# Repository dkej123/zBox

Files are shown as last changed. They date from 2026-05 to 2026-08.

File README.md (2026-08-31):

# zBox

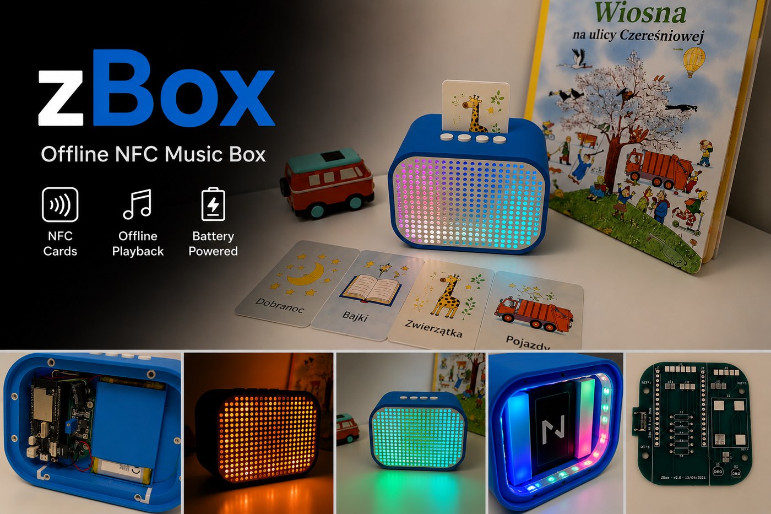
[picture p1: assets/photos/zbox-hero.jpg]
zBox audio box


zBox is an offline-first ESP32 NFC audio box: tap a card to play an MP3 from microSD, use
four physical buttons for playback and modes, and manage music and mappings from a small
FastAPI web portal. Wi-Fi is needed only for provisioning, synchronization, and maintenance.

> [!CAUTION]
> The manufactured PCB and Gerbers are legacy **v2.0 (April 2026)**. They predate the current
> schematic's July load-switch changes and are not a turnkey version of that schematic. A
> build from these Gerbers needs manual off-board wiring; read
> [Hardware status](docs/hardware-status.md) before ordering boards.

## What you need

- [ ] Lolin D32 Pro (ESP32), PN532 SPI NFC module, NS4168 I2S amplifier, and 4–8 Ω speaker
- [ ] MT3608 boost module, 12-pixel WS2812B strip/panel, and four momentary buttons
- [ ] 3.7 V LiPo, USB-C power/charging connection, hookup wire, PCB/protoboard, and solder
- [ ] Printed enclosure parts, M3 heat-set inserts, M3/M4 screws, and suitable filament
- [ ] FAT32 microSD card, NFC cards/tags, and optional Bluetooth headphones or speaker
- [ ] USB cable, soldering tools, multimeter, and a computer with PlatformIO
- [ ] Docker-capable host on the same network (a Raspberry Pi is a good fit)

See the [complete BOM](docs/bom.md) for values, footprints, quantities, and revision notes.

## Quick start

### 1. Clone everything

```bash
git clone --recursive https://github.com/dkej123/zBox.git
cd zBox
```

If you already cloned without submodules, run `git submodule update --init --recursive`.

### 2. Assemble the hardware

Print the [STL enclosure parts](hardware/stl/) and follow the
[printing notes](hardware/printing_tips.md). Wire the modules using the
[hardware reference](docs/hardware.md), accounting for the
[v2.0 PCB limitations](docs/hardware-status.md). Check polarity and shorts before power-up.

### 3. Prepare storage and flash

Format a microSD card as FAT32, insert it into the Lolin D32 Pro, connect USB, then run:

```bash
cd esp32
pio run -e lolin_d32_pro -t upload
cd ..
```

There is no compile-time server address. The device exposes its own sync service over Wi-Fi.

### 4. Start the server

```bash
docker compose up -d --build
curl http://localhost:8000/api/health
```

Open `http://<server-host>:8000`. The optional `ZBOX_IP` environment value is only a fallback;
the preferred setup is saving the device address in the portal.

### 5. Provision Wi-Fi

Hold buttons `A+B` for about two seconds to enter Sync Mode. On first use, join the
`zBox-Sync` Wi-Fi network from a phone or laptop and complete its captive portal with the
credentials for the same network as the server. Note the device IP shown by your router or
serial monitor.

### 6. Add the device and content

In the admin portal:

1. Open **Device**, enter the zBox IP address or `zbox.local`, and save it.
2. Open **Songs** and upload MP3 files.
3. Open **Tags**, scan or enter an NFC UID, name it, and assign a track.
4. Return to **Device** and start synchronization.

When sync finishes, hold `A+B` to return to normal operation. Present the registered card;
playback should start locally from microSD through the NS4168 speaker.

## Controls

| Input | Action |
| --- | --- |
| `A` or `B`, click | Play/pause |
| `A`, double-click | Previous track |
| `B`, double-click | Next track |
| `A`, hold ~2 s | Toggle optional Bluetooth output |
| `B`, hold ~2 s | Toggle NFC Card/Music playback mode |
| `C` / `D`, click | Volume down / up |
| `C`, hold ~2 s | Show battery level |
| `D`, hold ~1 s | Enter deep sleep |
| `A+B`, hold ~2 s | Enter or leave Sync Mode |
| Sleeping: hold `D` ≥400 ms | Wake normally |
| Sleeping: hold `C+D` ≥400 ms | Wake into night-light mode |

The device currently powers down with ESP32 deep sleep. The proposed zero-standby-current
soft latch and mechanical travel switch are design work only; they have not been built or
bench-validated. See [Hardware status](docs/hardware-status.md).

## Repository map

| Path | Contents |
| --- | --- |
| [`esp32/`](esp32/) | PlatformIO firmware and native tests |
| [`server/`](server/) / [`web/`](web/) | FastAPI server and browser admin |
| [`hardware/pcb/kicad/`](hardware/pcb/kicad/) | Current schematic plus legacy v2.0 PCB layout |
| [`hardware/pcb/gerbers/`](hardware/pcb/gerbers/) | Legacy v2.0 manufacturing outputs |
| [`hardware/stl/`](hardware/stl/) | Printable enclosure parts |
| [`hardware/cad/fusion360/step/`](hardware/cad/fusion360/step/) | Editable mechanical STEP export |

## Documentation

- [Build guide](docs/build-guide.md)
- [Bill of materials](docs/bom.md)
- [Hardware status and revision gap](docs/hardware-status.md)
- [Hardware wiring](docs/hardware.md)
- [Firmware](docs/esp32-firmware.md)
- [Server](docs/server.md)

`karty.pdf` and [`cards_images/`](cards_images/) are optional printable card assets. The project
owner holds the rights needed to publish the owner-created card graphics and other media here.

## License

The [MIT license](LICENSE) covers the repository's code, hardware design files, documentation,
and owner-created media unless a file states otherwise. Third-party submodules and dependencies
retain their own licenses. This is a DIY design: independently review electrical and battery
safety before manufacturing or giving a completed device to a child.

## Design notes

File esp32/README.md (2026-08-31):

# zBox ESP32 Firmware

Firmware for the ESP32 Lolin D32 Pro using PlatformIO and the mixed `arduino, espidf` framework setup.

## Quick start

```bash
pio run
pio run -t upload
pio device monitor
```

## Before flashing

- review `ENABLE_LEDS`
- verify the board and partition settings match your hardware
- read the [hardware revision status](../docs/hardware-status.md); the legacy v2.0 PCB needs
  manual wiring for the current firmware's load switches

There is no compile-time server address. Enter Sync Mode with a two-second `A+B` hold,
provision Wi-Fi through the `zBox-Sync` captive portal, and save the device address in the
server's **Device** page. `ZBOX_IP` is only a server-side fallback.

The main project constants live in [`src/zbox_config.h`](src/zbox_config.h).

## Documentation

- [Firmware architecture](../docs/esp32-firmware.md)
- [Hardware notes](../docs/hardware.md)
- [Build guide](../docs/build-guide.md)
- [Server API and deployment](../docs/server.md)

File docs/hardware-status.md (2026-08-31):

# Hardware status and revision gap

The repository intentionally keeps both the manufactured files and the newer design work.
They are not the same revision and must not be presented as interchangeable.

## Status matrix

| Artifact or feature | Status | Builder impact |
| --- | --- | --- |
| PCB layout and Gerbers | **Legacy v2.0, April 2026; manufactured** | Available for reference/reproduction, but older than the current schematic and not turnkey |
| Current KiCad schematic | **Newer design, July 2026 additions** | Documents the intended modules, button pull-ups, and NFC/amplifier load switching |
| Current firmware | **Implements July load-switch control** | Expects `NS_EN=GPIO15`, `NFC_EN=GPIO12`, current button mapping, and deep-sleep sequencing |
| v2.0 manual build | **Possible with off-board wiring** | Builder must add and verify the missing current-schematic circuits manually |
| Soft power latch / travel switch | **Future, unimplemented, unverified** | Excluded from the base build and BOM total; do not assume zero-current off |

## What v2.0 does not contain

The routed [`zbox.kicad_pcb`](../hardware/pcb/kicad/zbox.kicad_pcb) and files in
[`hardware/pcb/gerbers/`](../hardware/pcb/gerbers/) do **not** contain the current schematic's:

- `Q3`, `Q4`;
- `R9` through `R14`;
- `C2` through `C6`;
- `J13`; or
- `NS_EN`, `+3V3_NS`, `NFC_EN`, and `NFC_GND_SW` nets.

The v2.0 PCB instead retains older JBL-era references such as `Q1`, `R3`, `R6`, `R7`, `J10`,
and `J12`. Those are not the current firmware's default NS4168 audio design.

Practically, manufacturing the checked-in Gerbers produces legacy v2.0—not a board matching
the current schematic. The two load switches, button pull-ups, NS4168 connection, decoupling,
and affected nets must be wired off-board and continuity-checked against
[hardware wiring](hardware.md). A future PCB revision should synchronize schematic, layout,
Gerbers, BOM, firmware pins, and a physically tested assembly before it is called turnkey.

## Current power-off behavior

Today, all shutdown paths end in ESP32 deep sleep. Firmware gates the LED supply and, when
the July off-board circuits are present, the NS4168 and PN532 supplies. The D32 Pro itself is
still powered, so this is not a physical battery disconnect and not a zero-current-off state.

## Planned power-latch improvement

The proposed upgrade combines:

- a mechanical SPST kill switch in series with `BAT+` for travel/storage;
- a self-holding soft latch, set by the existing `BTN_D`, that remains on across software,
  watchdog, panic, and brownout resets;
- an active-HIGH, roughly 100–120 ms kill pulse from `GPIO2` after graceful shutdown; and
- firmware changes replacing deep-sleep wake/off tails while preserving the current LED
  hold-to-confirm behavior and `C+D` night-light selection.

This is design intent only. It is absent from the schematic, PCB, Gerbers, and firmware.
Before adoption it needs electrical review plus bench tests for latch SET/HOLD/KILL behavior,
GPIO2 boot strapping, reset survival, button isolation from battery voltage, off-state leakage,
switch/MOSFET current and thermal margin, idle timeout, low-battery cutoff, and every shutdown
path. Proposed parts are isolated in the optional section of the [BOM](bom.md).

## Release policy

The existing files remain available as legacy v2.0. Do not publish a v1.0 hardware release
until a synchronized successor PCB has been manufactured and physically validated.

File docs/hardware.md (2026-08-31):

# zBox hardware wiring

This is the wiring reference for the **current schematic and firmware**. It is newer than the
manufactured v2.0 PCB/Gerbers. Read [hardware status](hardware-status.md) before building and
use the [BOM](bom.md) for exact values and footprints.

## Main blocks

```text
NFC card -> PN532 -> ESP32 Lolin D32 Pro -> microSD
                         |       |
                         |       +-> WS2812B LEDs through MT3608
                         +-> I2S -> NS4168 -> 4–8 ohm speaker
                         +-> optional Bluetooth A2DP output
```

Playback is offline. Wi-Fi is active in Sync Mode for provisioning, content transfer,
diagnostics, and maintenance.

## ESP32 pin assignments

| GPIO | Function | Notes |
| ---: | --- | --- |
| `0` | PN532 MOSI | Software SPI |
| `4` | microSD CS | D32 Pro onboard slot |
| `5` | PN532 SS | Software SPI |
| `12` | `NFC_EN` | Q4 low-side switch; active HIGH |
| `13` | NS4168 DIN | I2S data |
| `14` | WS2812B DIN | 12 LEDs by default |
| `15` | `NS_EN` | Q3 high-side switch; active LOW/Hi-Z off |
| `21` | PN532 MISO | Software SPI |
| `22` | PN532 SCK | Software SPI |
| `25` | Button C | Internal pull-up, volume down/battery preview |
| `26` | Button D | Internal pull-up, volume up/sleep/deep-sleep wake |
| `27` | `LED_EN` | Q2 high-side switch; active LOW |
| `32` | NS4168 BCLK | I2S bit clock |
| `33` | NS4168 LRCK/WS | I2S word select |
| `35` | Battery ADC | D32 Pro onboard divider |
| `36` | Button A | Input-only; external 10 kΩ pull-up required |
| `39` | Button B | Input-only; external 10 kΩ pull-up required |

All buttons are active LOW. Current behavior is documented in the root [README](../README.md)
and verified by the native button-decoder tests.

## D32 Pro header positions

With USB at the bottom, count each 16-pin header from top to bottom as `L1..L16` and
`R1..R16`.

| Position | Connection | Position | Connection |
| --- | --- | --- | --- |
| `L1` | `+3V3` | `R1` | `GND` |
| `L3` | `GPIO36 / BTN_A` | `R3` | `GPIO22 / PN532_SCK` |
| `L4` | `GPIO39 / BTN_B` | `R6` | `GPIO21 / PN532_MISO` |
| `L6` | `GPIO32 / I2S_BCLK` | `R9` | `GPIO5 / PN532_SS` |
| `L7` | `GPIO33 / I2S_LRCK` | `R12` | `GPIO4 / SD_CS` |
| `L8` | `GPIO25 / BTN_C` | `R13` | `GPIO0 / PN532_MOSI` |
| `L9` | `GPIO26 / BTN_D` | `R14` | `GPIO2` (unused today) |
| `L10` | `GPIO27 / LED_EN` | `R15` | `GPIO15 / NS_EN` |
| `L11` | `GPIO14 / LED data` | `R16` | `GND` |
| `L13` | `GPIO13 / I2S_DOUT` |  |  |
| `L15` | `USB / 5 V` |  |  |
| `L16` | `BAT / VBAT` |  |  |

## Audio and LEDs

Connect NS4168 `BCLK`, `LRCK/WS`, and `DIN` to GPIO32, GPIO33, and GPIO13 respectively. Its
VDD comes from switched `+3V3_NS`, not directly from `+3V3`. Fit the bulk and ceramic
decoupling at the module and keep I2S/speaker wiring short.

The MT3608 takes the battery rail and supplies 5 V to the LED strip. Adjust it to 5 V with
the LEDs disconnected. Q2 gates the boost input with `LED_EN=GPIO27`; `R8=100k` holds the
P-MOSFET off. WS2812B data is GPIO14 and the configured count is 12.

## Current-schematic load switches

These circuits exist in the July schematic and firmware but **not** on the legacy v2.0 PCB.
They must be wired off-board when v2.0 is used.

### NS4168 high-side switch

| Part | Connection |
| --- | --- |
| `Q3` AO3401A | source -> `+3V3`; drain -> `+3V3_NS`; gate -> `NS_EN_G` |
| `R11` 100 kΩ | `NS_EN_G` -> `+3V3` (default off) |
| `R12` 10 kΩ | GPIO15 -> `NS_EN_G` |
| `C6` 100 nF | `NS_EN_G` -> `+3V3` (soft-start) |
| `C2` 10 µF, `C3` 100 nF | `+3V3_NS` -> GND, close to NS4168 |
| `J13` | NS4168 pad: VDD=`+3V3_NS`, GND, BCLK=32, LRCK=33, DIN=13 |

GPIO15 is active LOW. Firmware uses Hi-Z for off so `R11` can close Q3 without a boot glitch.
The `R12+C6` soft-start is important: switching the amplifier abruptly can collapse the ESP32
3.3 V rail and cause a brownout loop.

### PN532 low-side switch

| Part | Connection |
| --- | --- |
| `Q4` AO3400A | drain -> `NFC_GND_SW`; source -> GND; gate -> `NFC_EN_G` |
| `R13` 100 kΩ | `NFC_EN_G` -> GND (default off and safe boot strap) |
| `R14` 100 Ω | GPIO12 -> `NFC_EN_G` |
| `C4` 10 µF, `C5` 100 nF | `+3V3` -> `NFC_GND_SW`, close to PN532 |
| `J3` | PN532 VDD=`+3V3`; GND=`NFC_GND_SW`; SPI pins as listed above |

GPIO12 is active HIGH. Before switching Q4 off, firmware makes the PN532 SPI lines high
impedance so the floating module ground cannot back-power the ESP32 through protection diodes.

## Power and safety notes

- `C1` is a 470 µF polarized capacitor in the current schematic; observe polarity.
- `R1` and `R2` are the two 5.1 kΩ USB-C CC resistors.
- `R9` and `R10` are the external 10 kΩ pull-ups required by input-only GPIO36/39.
- The checked-in PCB has older JBL wiring and different Q2 labeling/value; use the current
  schematic as the wiring authority but never assume its additions are routed in v2.0.
- The project uses deep sleep, not a physical power disconnect. The proposed latch is
  [future and unverified](hardware-status.md#planned-power-latch-improvement).
- Review LiPo charging, wire gauge, insulation, polarity, and enclosure fire/impact risk for
  your parts. Do not leave a first assembly charging unattended.

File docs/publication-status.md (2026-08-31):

# Publication status

Last updated: 2026-08-31

This document records the current state of the repository-publication work. All changes
described here exist only on the local `public-ready` branch. The working `main` branch and
its staged, unstaged, untracked, and submodule firmware changes have not been modified.

## Completed

- Replaced the root README with a concise English project overview and end-to-end quick start.
- Added a reproducible build guide, current-schematic BOM, and hardware revision status.
- Documented the difference between the manufactured legacy PCB/Gerbers v2.0, the current
  schematic, current firmware expectations, and the unimplemented power-latch proposal.
- Updated firmware, server, hardware, and test documentation to match current button,
  provisioning, sync, sleep, and wake behavior.
- Removed obsolete debugging plans, completed checklists, generic agent notes, and the binary
  embedded-refactoring skill.
- Removed the obsolete Docker Compose `version` field and expanded `.gitignore` for runtime,
  build, credential, backup, and local-agent files.
- Preserved the MIT license, printable card files, CAD, STL, PCB, schematic, and legacy Gerbers.
- Updated the GitHub repository description and topics. No release was created.

## History and identity

- The complete history reachable from `public-ready` was rewritten so the former work address
  is absent from both author and committer metadata.
- Rewritten commits use the authenticated GitHub noreply identity where that work address had
  previously appeared. New publication commits also use the noreply identity.
- The public GitHub `main` branch has not been replaced yet, so its old history remains visible
  until a separately approved history replacement is performed.
- A local recovery bundle of the pre-rewrite publication branch was created outside the
  repository. It must not be published because it intentionally contains the old history.

## Submodule decision

The repository previously pinned `esp32/lib/ESP32-A2DP` to a locally created commit that was
not available from the configured public upstream. On `public-ready`, the gitlink now points to
its publicly available parent, `4783cf6dfe107d00873f5883d3350de1981f253b`. This makes a clean
recursive checkout possible without creating or maintaining a separate fork. Local submodule
work on `main` was not removed or changed.

## Validation completed

- Root README length: 134 lines.
- All retained project Markdown links resolve locally.
- `docker compose config`, image build, persistence mounts, and `/api/health` smoke test pass.
- Python compilation and container import checks pass.
- PlatformIO native tests pass: 132 `native` plus 28 `native_btndec`, 160 total.
- Release firmware build `lolin_d32_pro` passes.
- Debug firmware build `lolin_d32_pro_debug` passes.
- A clean recursive checkout successfully fetches the public ESP32-A2DP revision.
- The BOM was cross-checked against current KiCad references and footprints.
- The history reachable from `public-ready` contains no former work-address metadata.
- The original `main` working tree was checked after the work and remains unchanged.

## Remaining publication steps

1. Review the dependency behavior after dropping the private ESP32-A2DP patch, especially
   Bluetooth AVRCP volume notifications, on physical hardware.
2. Decide when to publish `public-ready` and when to replace public `main` with its rewritten
   history. Replacing `main` will require a coordinated force-push and fresh clones or hard
   resets for any existing collaborators.
3. Repeat the secret/history scan against the exact refs intended for publication immediately
   before pushing.
4. Do not create a v1.0 release until a synchronized successor PCB has been manufactured and
   physically verified.

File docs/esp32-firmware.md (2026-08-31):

# ESP32 Firmware

Firmware for the zBox NFC audio device, built with PlatformIO on the ESP32 Lolin D32 Pro using the mixed `arduino, espidf` framework.

## Build environments

| Environment | Purpose |
|---|---|
| `lolin_d32_pro` | Main firmware for the device — **logging compiled out** (default) |
| `lolin_d32_pro_debug` | Main firmware **with logging enabled** (`LOG_ENABLED`) |
| `lolin_d32_pro_ota` | `lolin_d32_pro` flashed over the air (espota) |
| `lolin_d32_pro_debug_ota` | `lolin_d32_pro_debug` flashed over the air (espota) |
| `native` | Unit tests (reducer, state logic) — runs on the host |
| `native_btndec` | Unit tests for the button decoder module |

```bash
pio run                              # build release firmware (no logs)
pio run -t upload                    # flash to device
pio device monitor                   # serial monitor at 115200 baud

pio run -e lolin_d32_pro_debug       # build with logging enabled
pio device monitor -b 921600         # serial monitor for the debug build

pio test -e native                   # run native unit tests
```

## Compile-time configuration

All device-specific constants live in [`esp32/src/zbox_config.h`](../esp32/src/zbox_config.h). The ones you are most likely to change before flashing:

| Constant | Default | Purpose |
|---|---|---|
| `AUDIO_I2S_BCLK` | `32` | NS4168 bit clock pin |
| `AUDIO_I2S_LRCK` | `33` | NS4168 left/right clock pin |
| `AUDIO_I2S_DOUT` | `13` | NS4168 data output pin |
| `ENABLE_LEDS` | `true` | Enable or disable the WS2812B LED panel |

GPIO assignments and tuning constants (timeouts, ADC factors, volume steps) are also defined there.

## Logging

Logging is controlled by the compile-time flag `LOG_ENABLED`, defined only in the `_debug` environments. The macros and persistent-log backend live in [`esp32/src/util/logging.h`](../esp32/src/util/logging.h) and [`esp32/src/util/persistent_log.cpp`](../esp32/src/util/persistent_log.cpp); the flag is wired up in [`esp32/platformio.ini`](../esp32/platformio.ini).

**Release** (`lolin_d32_pro`, the default env) — logging is compiled out entirely. The `LOGI/LOGW/LOGE/LOGC` macros expand to `((void)0)` (arguments are never evaluated) and `plog*`/`logWritef` early-return. No `Serial`/`vsnprintf` cost, no RTC/SD persistence, and about 12 KB less flash. The trade-off is losing the post-crash "RECOVERED FROM RTC" dump.

**Debug** (`lolin_d32_pro_debug`) — logging is on. Serial runs at 921600 baud with an enlarged TX buffer, and writes are **non-blocking**: a line is dropped rather than stalling a task when the TX buffer is full, so bursts of logs can't add jitter to the audio/BT path. Persistent lines are still kept in the RTC ring even when the Serial print is skipped.

Sync mode is separate: the `/diag/logs` HTTP ring buffer stays populated in every build, and only its `Serial` output is gated behind `LOG_ENABLED`.

## Architecture

The firmware uses a **reducer + dispatcher** architecture. All application logic lives in a pure function:

```
reduce(AppState, Event) → (next AppState, Effects[])
```

The dispatcher executes effects (start audio, enter/leave BT headphones mode, sleep, sync-mode restart) and feeds feedback events back into the queue. No module owns hidden state — all state is in `AppState`.

### Modules

| Module | Responsibility |
|---|---|
| `state` | `AppState` definition and zero-init |
| `reducer` | Pure `reduce()` function, no I/O |
| `dispatcher` | FreeRTOS task, event queue, effect execution |
| `audio` | SD card audio playback over local I2S with optional BT headphones routing and zBox-side PCM volume attenuation |
| `nfc_module` | PN532 NFC reader, tag detection loop |
| `playback` | Track list management and position tracking |
| `button_adapter` | Button press detection, debounce, combo and long-press decoding |
| `sleep` | Deep sleep entry, wake protocol, night-light mode |
| `sync_mode` | Wi-Fi service mode used by the admin portal for push sync, logs, and maintenance |
| `leds` | WS2812B LED scenes derived from `AppState` |
| `bt_adapter` | Temporary BT headphones-mode lifecycle and connection edges |
| `volume` | Output volume persistence and apply path |
| `battery` | ADC battery level reading |
| `sd_storage` | SD card init, file listing, path helpers |
| `persistent_log` | Diagnostic log written to SD |
| `logging` | Serial log helpers |
| `helpers` | Miscellaneous utilities |
| `musicbox_config` | Runtime configuration loaded at boot |

### Event flow

```
ISR / NFC task / timer
        │  Event
        ▼
   Event queue (FreeRTOS)
        │
        ▼
   Dispatcher task
        │  reduce(state, event) → (next_state, effects)
        ├─ updates AppState
        └─ executes Effects
               │  async result
               └─ feedback Event → queue
```

## Sleep and wake

The device enters deep sleep on:
- idle timeout (10 minutes without playback)
- BTN_D hold for about 1 second (normal sleep with shutdown animation)
- sustained critical battery voltage

Local audio is the default output on every boot. A long hold on `BTN_A` enables a temporary Bluetooth headphones mode; when the mode exits or the device restarts, output returns to local I2S.

Output volume is owned by zBox in both modes. For BT headphones the firmware scales PCM before it reaches the transport; it does not rely on remote headphone volume support. The legacy NVS key remains `bt_volume` only for backward compatibility with devices already in the field.

Wake from deep sleep requires holding BTN_D for at least 400 ms. Releasing earlier returns to
deep sleep. Hold BTN_C at the same time to boot into night-light mode.

## Tests

Native tests cover reducer transitions and state invariants without requiring hardware. Run with:

```bash
pio test -e native
pio test -e native_btndec
```

Hardware-only behavior—sleep current, wake cycles, Bluetooth reconnects, radio coexistence,
and peripheral power sequencing—still requires testing on a physical unit.

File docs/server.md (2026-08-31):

# zBox Server

The server is a FastAPI application with a SQLite database and a browser-based admin portal. It manages the track library, figurine mappings, system sound assignments, and ESP32 sync operations.

## Stack

- Python 3.11
- FastAPI
- SQLAlchemy
- SQLite in `./data/zbox.db`
- React-based static admin portal served from `web/`
- Docker / Docker Compose for deployment

## Directory layout

```text
server/
├── main.py
├── paths.py
├── database.py
├── device_sync.py
├── models.py
├── system_sounds.py
├── requirements.txt
├── routers/
│   ├── admin.py
│   └── api.py
```

```text
web/
├── index.html
├── app.jsx
├── data.jsx
├── styles.css
└── section-*.jsx
```

## Data model

- `Track`: library entry with title, stored filename, and creation timestamp.
- `Figurine`: NFC UID mapped to an optional track. Referred to as "NFC Tag" in the admin UI and user-facing documentation.
- `SystemSound`: named event slot such as `power_on` or `ready`, optionally assigned to an MP3 file.

## Public API used by the ESP32

| Method | Path | Purpose |
|---|---|---|
| `GET` | `/api/play/{nfc_uid}` | Legacy online playback response. Kept for compatibility. |
| `GET` | `/api/stream/{track_id}` | Legacy track streaming by database ID. |
| `GET` | `/api/stream/file/{filename}` | File download endpoint used by ESP32 sync. |
| `GET` | `/api/sync` | Sync manifest containing figurines, tracks, and assigned system sounds. |
| `GET` | `/api/health` | Health endpoint. |
| `GET` | `/api/system_sounds/{sound_name}` | Preview endpoint for assigned system sounds. |

## Admin API

The `/admin/...` routes provide:

- track upload, trimming, delete, and background YouTube import
- figurine CRUD and track assignment
- system sound upload and reset
- device status lookup
- device sync planning and execution
- diagnostic log browsing and download

## Sync diagnostics

The backend now emits structured application logs for device connectivity and sync execution. The most useful log streams are:

- `zbox.main`: server startup and base runtime initialization
- `zbox.admin`: admin-triggered sync task lifecycle, per-stage progress, offline detection, log download failures, and restart requests
- `zbox.device_sync`: direct HTTP interactions with the ESP32, sync plan generation, per-file upload start/finish, delete operations, metadata writes, and retry-after-connection-reset events

When investigating a failed or interrupted sync, look for:

- the sync `task_id`
- configured device IP and resolved `device_id`
- current sync `stage`
- `current_file` and per-file upload progress
- connection errors raised while polling `/diag/status`, `/diag/files`, `/diag/logs`, or `/diag/upload`

## Sync task status payload

The admin sync status response includes both aggregate progress and per-file progress for uploads.

Important fields on `GET /admin/devices/{device_id}/sync/{task_id}/status`:

- `progress`: whole-task progress in percent
- `stage`: current sync stage such as `fetching_device_state`, `uploading_audio`, or `writing_system_sounds`
- `current_file`: file currently being uploaded
- `current_file_progress`: percent for the current file
- `sync_files`: ordered list of files scheduled for upload, each with:
  - `path`
  - `status`: `pending`, `uploading`, or `uploaded`
  - `progress`

The web admin uses `sync_files` to render the live upload queue so short connectivity glitches are easier to correlate with the exact file being transferred.

## Runtime model

```bash
docker compose up -d --build
```

The server is intended to run in Docker, not as a host-level Python process.

The compose setup mounts:

- `./music` to `/app/music`
- `./data` to `/app/data`
- `./web` to `/app/web`

Set the ESP32 address from the portal's **Device** page. It is persisted in
`./data/device_settings.json` and takes precedence over the optional `ZBOX_IP` value from a
local `.env` file. No firmware-side server address setting is required.

## Deployment

The default deployment shape is a Linux host running Docker:

```bash
docker compose up -d --build
```

Avoid hardcoding personal hostnames or private IP addresses in documentation or scripts.

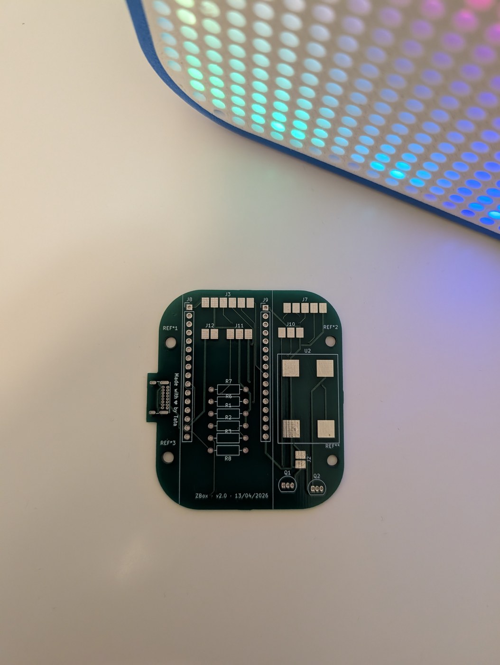
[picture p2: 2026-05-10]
assets/photos/zbox-pcb.jpg

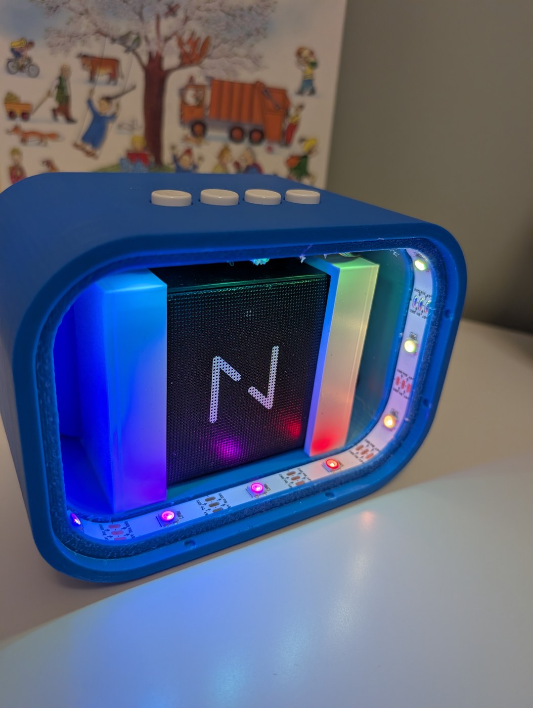
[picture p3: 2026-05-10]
assets/photos/zbox-internals.jpg

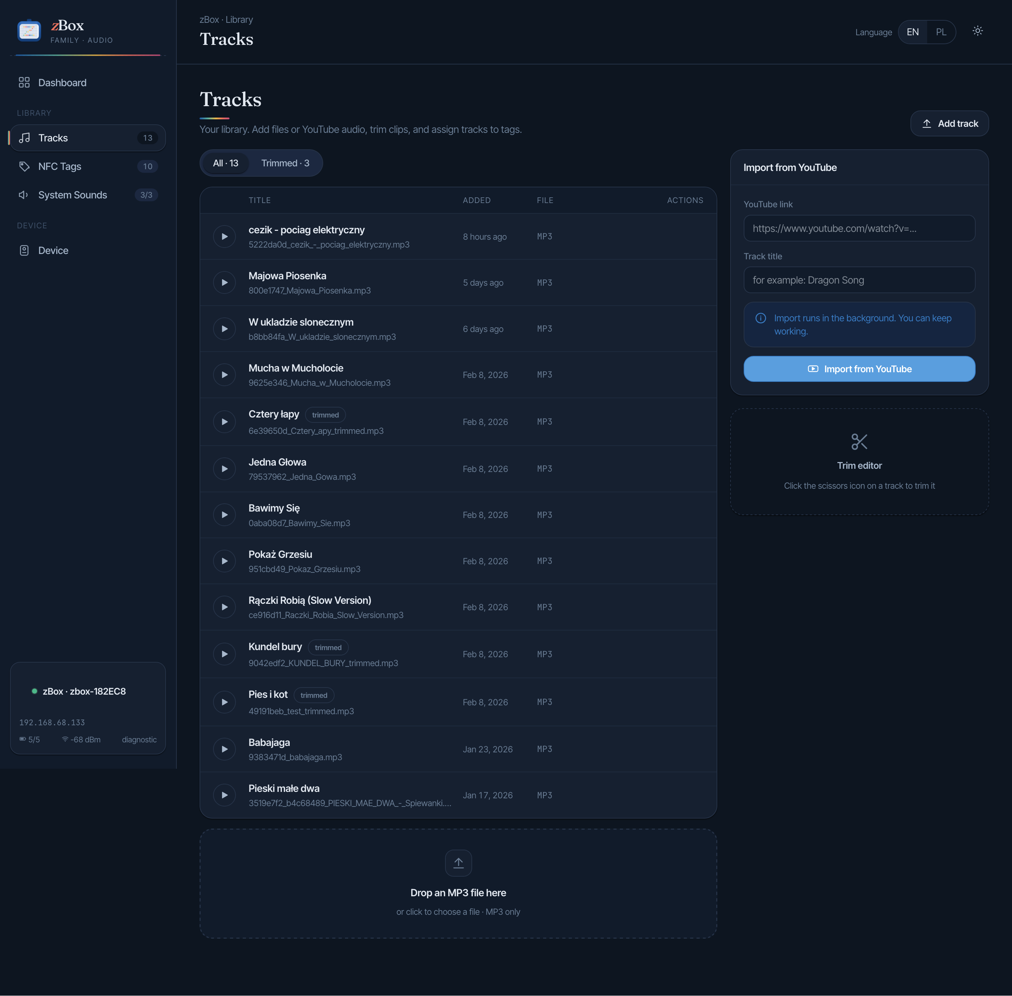
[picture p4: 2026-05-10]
assets/photos/admin-tracks.png

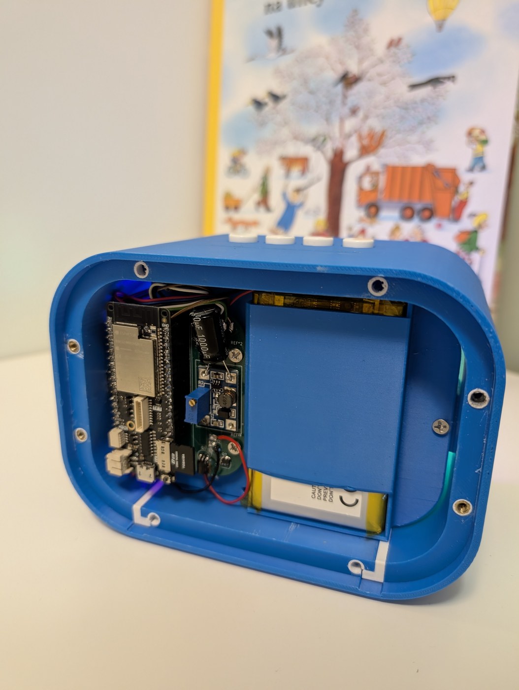
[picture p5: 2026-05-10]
assets/photos/zbox-front-open.jpg

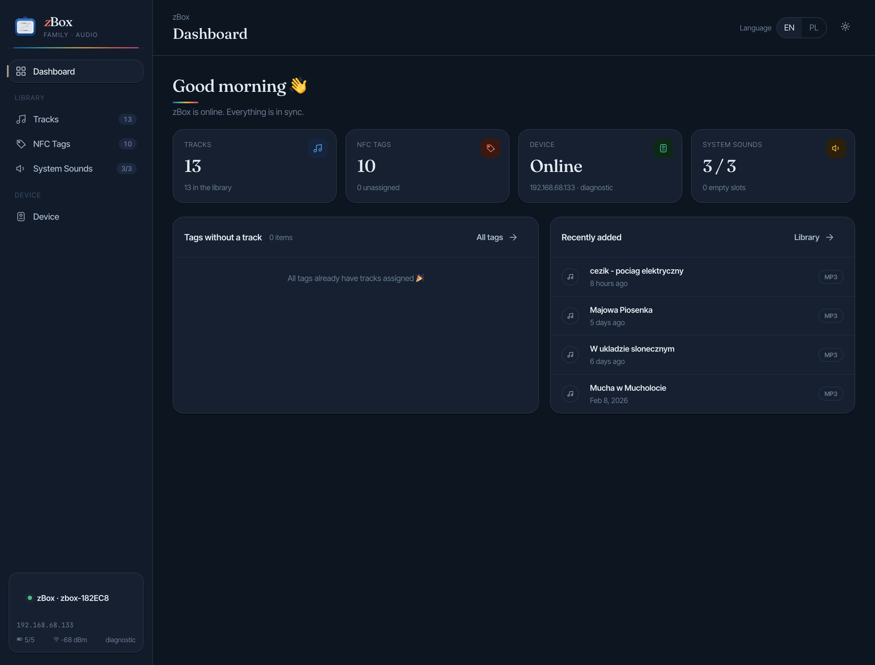
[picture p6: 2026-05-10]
assets/photos/admin-dashboard.png

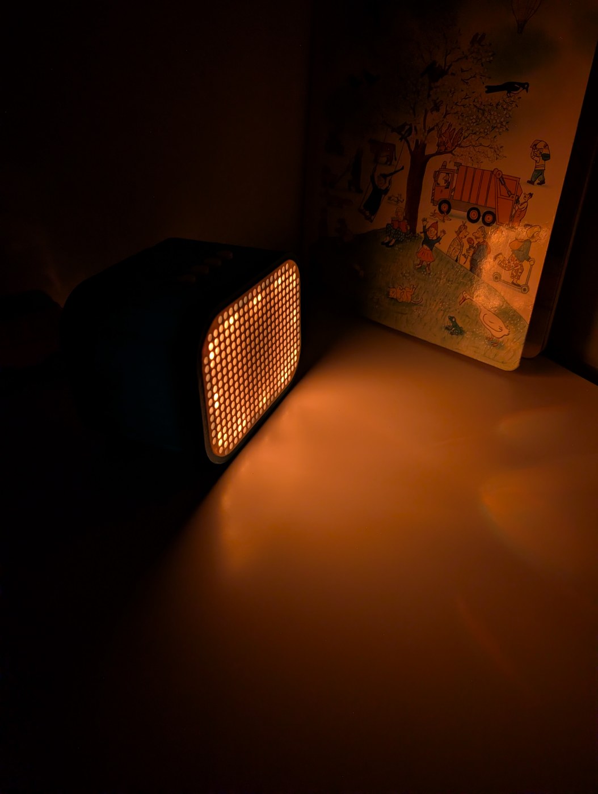
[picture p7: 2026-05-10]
assets/photos/zbox-light-mode.jpg

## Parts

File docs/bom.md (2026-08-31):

# zBox bill of materials

This BOM follows the **current KiCad schematic**. It is not a claim that the legacy v2.0
PCB/Gerbers contain those parts; see [hardware status](hardware-status.md). `PAD_*` references
are PCB wire pads, not separate purchased connectors. Verify module pinouts and footprints
against the exact parts you buy.

## Required modules and electrical parts

| Qty | Item | Notes |
| ---: | --- | --- |
| 1 | Lolin D32 Pro ESP32 board | Includes microSD slot and LiPo support; schematic `U1` |
| 1 | PN532 NFC module | Must support SPI; wired at `J3` |
| 1 | NS4168 I2S amplifier module | Wired at `J13` |
| 1 | 4–8 Ω speaker | Must fit the printed holder and amplifier rating |
| 1 | MT3608 boost module | Schematic `U2`; adjust to 5 V before LEDs are connected |
| 1 | 12-pixel WS2812B strip/panel | Wired at `J11` |
| 1 | GCT USB4085 USB-C receptacle | `J1`, exact `Connector_USB:USB_C_Receptacle_GCT_USB4085` footprint |
| 1 | 3.7 V LiPo, about 4000 mAh | Current enclosure fits about 8 × 50 × 80 mm; wired at `J2` |
| 4 | 12 × 12 × 7.3 mm momentary buttons | Four-pin TACT switches with caps; wired at `J7` |
| 2 | AO3401A P-MOSFET | `Q2`, `Q3`; `Package_TO_SOT_SMD:SOT-23` |
| 1 | AO3400A N-MOSFET | `Q4`; `Package_TO_SOT_SMD:SOT-23` |

## Exact current-schematic passives

| References | Qty | Value | KiCad footprint |
| --- | ---: | --- | --- |
| `R1`, `R2` | 2 | 5.1 kΩ | `Resistor_THT:R_Axial_DIN0207_L6.3mm_D2.5mm_P10.16mm_Horizontal` |
| `R8`, `R11`, `R13` | 3 | 100 kΩ | `Resistor_THT:R_Axial_DIN0207_L6.3mm_D2.5mm_P10.16mm_Horizontal` |
| `R9`, `R10`, `R12` | 3 | 10 kΩ | `Resistor_THT:R_Axial_DIN0207_L6.3mm_D2.5mm_P10.16mm_Horizontal` |
| `R14` | 1 | 100 Ω | `Resistor_THT:R_Axial_DIN0207_L6.3mm_D2.5mm_P10.16mm_Horizontal` |
| `C1` | 1 | 470 µF polarized | `Capacitor_THT:CP_Radial_D8.0mm_P3.50mm` |
| `C2`, `C4` | 2 | 10 µF polarized | `Capacitor_THT:CP_Radial_D5.0mm_P2.50mm` |
| `C3`, `C5`, `C6` | 3 | 100 nF ceramic | `Capacitor_THT:C_Disc_D5.0mm_W2.5mm_P5.00mm` |

The base electronics total is 9 resistors, 6 capacitors, and 3 MOSFETs, plus the modules,
receptacle, buttons, battery, LEDs, speaker, and board/wiring. Buy spares for small parts.

## PCB, wiring, and consumables

- one PCB made from the legacy v2.0 Gerbers **or** protoboard/custom wiring reviewed against
  the current schematic; the v2.0 board needs the documented manual additions
- insulated hookup wire, pin headers as required by the modules, solder, flux, heat-shrink,
  cable ties, double-sided tape or hot glue, and strain relief
- a safe USB power supply and USB data cable; use the D32 Pro's supported LiPo charging path

## Mechanical parts

- all seven STL designs in [`hardware/stl/`](../hardware/stl/): shell, wall, front and rear
  lids, NFC card slot, and left/right speaker holders
- enough PETG/PLA or another suitable filament for one enclosure
- M3 heat-set inserts and M3 screws for the rear cover
- M4 screws for the side wall and ESP32 mounting, adjusted to suit the printed parts
- button protoboard and colored caps

## Runtime requirements

- one FAT32 microSD card (4–16 GB is ample)
- at least one compatible NFC card/tag; printable owner-created designs are in
  [`cards_images/`](../cards_images/) and [`karty.pdf`](../karty.pdf)
- a Docker-capable host on the same network, such as a Raspberry Pi
- optional Bluetooth headphones or speaker for A2DP output

## Future/unverified power-latch upgrade — excluded from the base total

These parts describe a **planned circuit only**. No repository PCB contains it, firmware still
uses deep sleep, values are provisional, and the design requires schematic review and bench
validation before use.

| Qty | Proposed part | Intended role |
| ---: | --- | --- |
| 1 | SPST mechanical switch rated for battery current | Hard travel disconnect in series with `BAT+` |
| 1 | AO3415A or suitable low-RDS(on) P-MOSFET | Main high-side latch switch |
| 2 | Small NPN transistors or suitable N-MOSFETs | Self-hold and `GPIO2` kill stages |
| 3 | ~100 kΩ resistors | Gate pull-up, feedback, and base/gate pull-down |
| 2 | ~10 kΩ resistors | Gate/base current limiting |
| 1 | Momentary SET path reusing `BTN_D` with isolation | Power-on request without exposing GPIO26 to battery voltage |

The target behavior is a self-holding latch that survives MCU resets and turns off only after
an active-HIGH kill pulse on `GPIO2`. Do not count these parts, connect them to v2.0, or market
the feature as implemented until reset survival, shutdown, leakage, low-battery behavior, and
switch current have been measured on hardware.

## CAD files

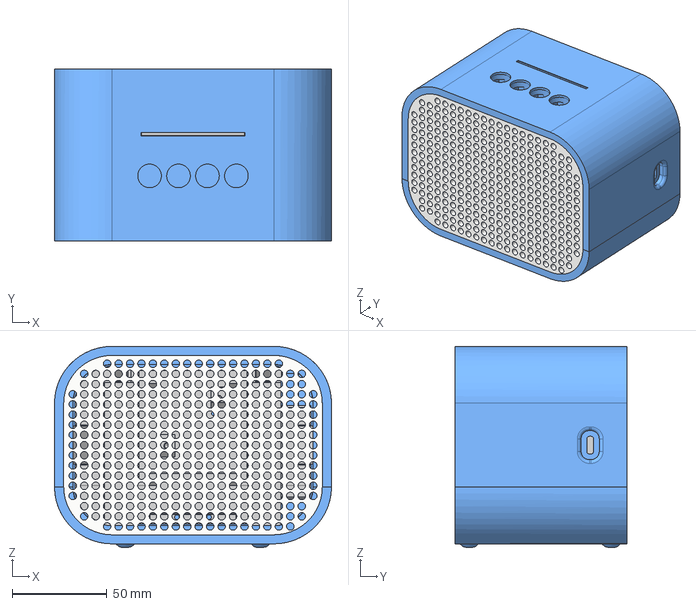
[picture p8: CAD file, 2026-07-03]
hardware/cad/fusion360/step/zbox_clear.step
146.4 x 91.0 x 106.4 mm

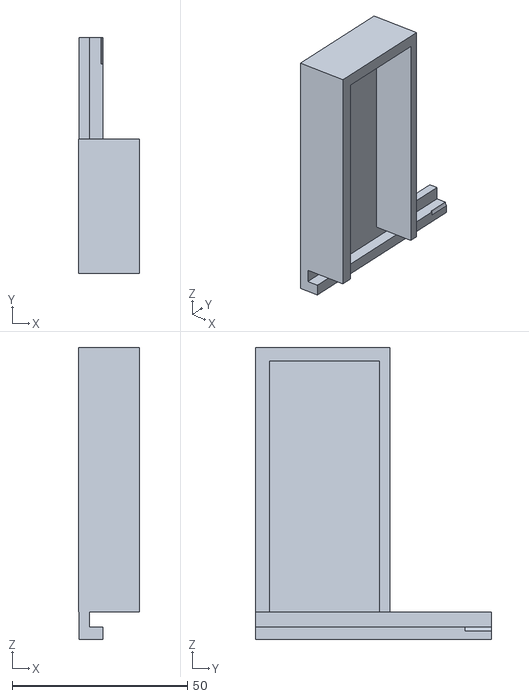
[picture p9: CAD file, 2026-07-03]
hardware/stl/speaker_holder_right_zbox_clear.stl
17.3 x 67.3 x 83.4

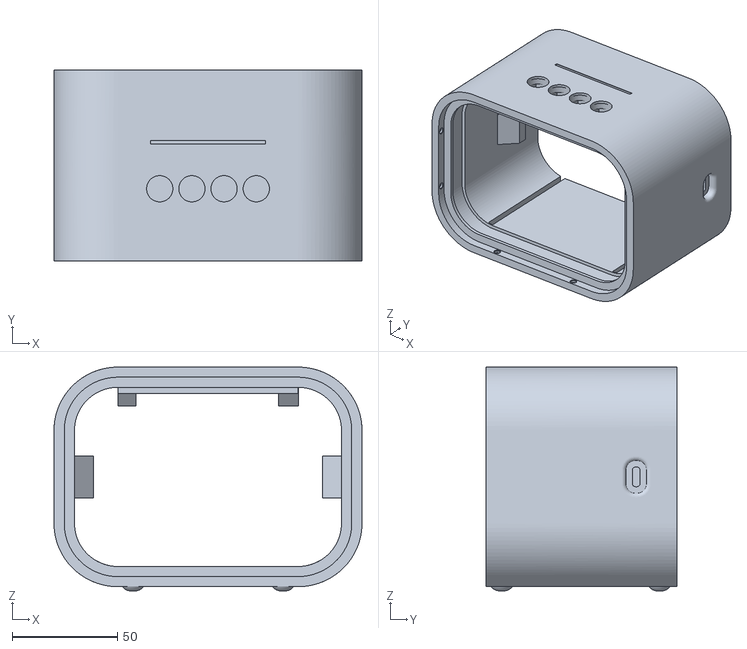
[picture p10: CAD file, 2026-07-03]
hardware/stl/shell_zbox_clear.stl
146.4 x 91.0 x 106.4

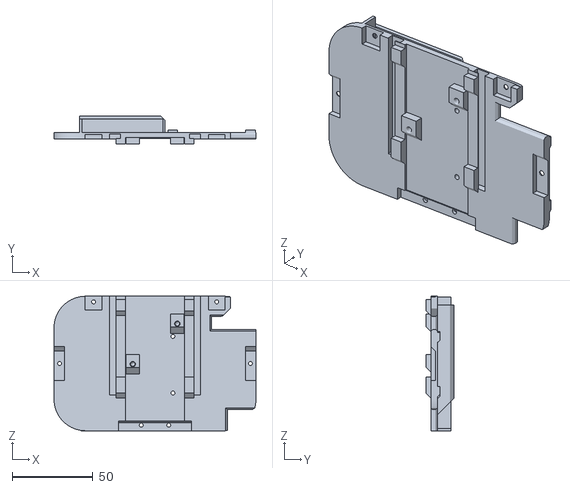
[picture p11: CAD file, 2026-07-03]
hardware/stl/wall_zbox_clear.stl
124.9 x 17.3 x 83.2

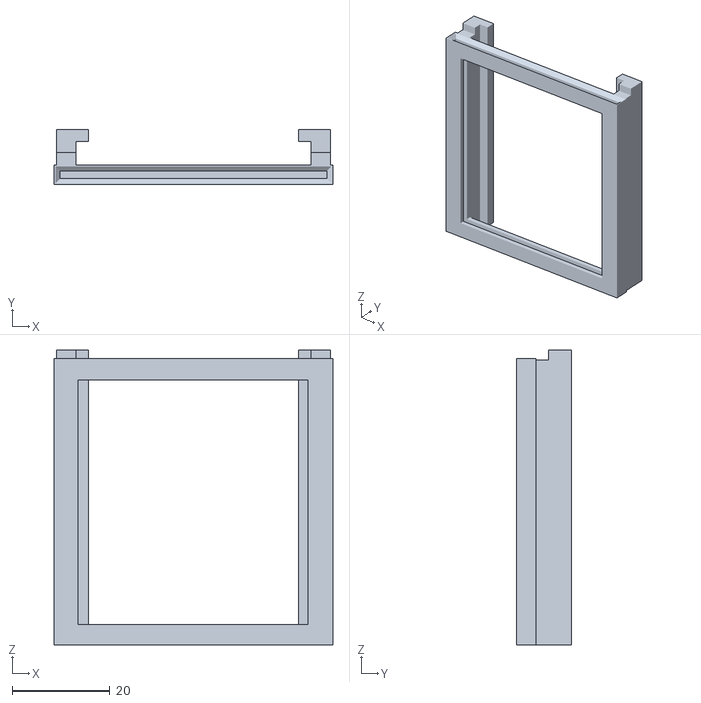
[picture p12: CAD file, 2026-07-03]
hardware/stl/nfc_card_slot_zbox_clear.stl
57.0 x 11.3 x 60.3

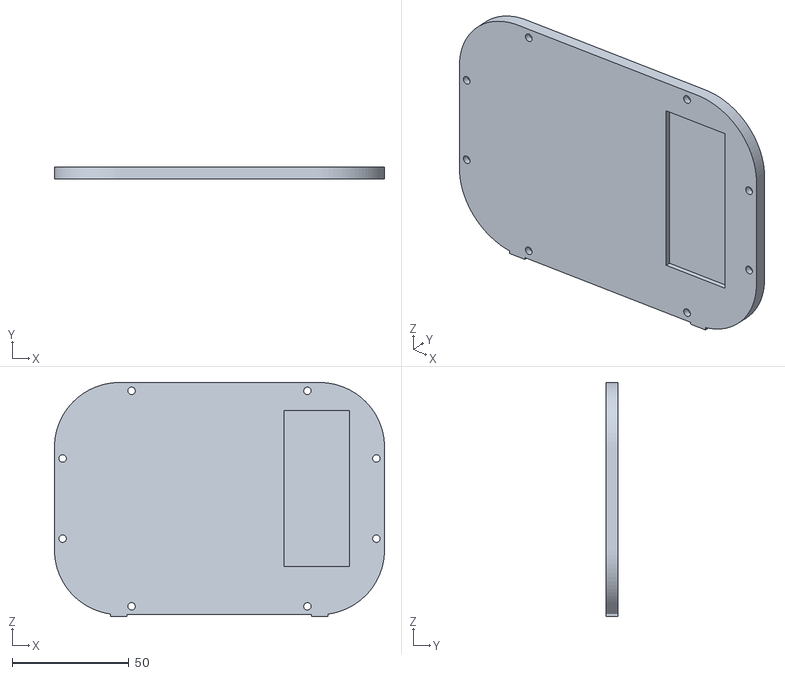
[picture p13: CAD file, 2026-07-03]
hardware/stl/rear_lid_zbox_clear.stl
141.5 x 5.00 x 100.4

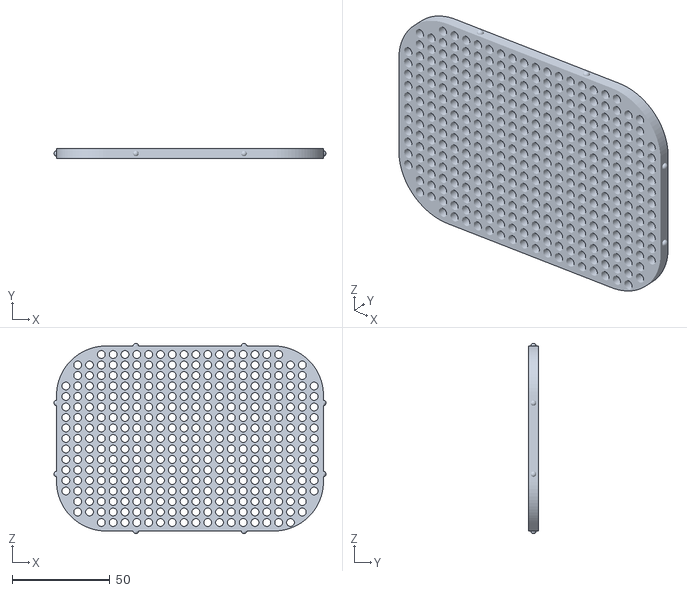
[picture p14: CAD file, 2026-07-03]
hardware/stl/front_lid_zbox_clear.stl
139.2 x 5.00 x 97.4

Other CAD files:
hardware/stl/speaker_holder_left_zbox_clear.stl

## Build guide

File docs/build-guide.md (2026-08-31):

# zBox build guide

This guide takes a new checkout from parts to the first NFC-triggered MP3. Read
[hardware status](hardware-status.md) first: the available PCB/Gerbers are legacy v2.0 and do
not contain every circuit in the current schematic.

## Prerequisites

- all required parts in the [BOM](bom.md), including a FAT32-capable microSD card and NFC tag
- enclosure parts from [`hardware/stl/`](../hardware/stl/) and the
  [printing notes](../hardware/printing_tips.md)
- soldering tools, multimeter, USB data cable, and a safe LiPo charging arrangement
- Git, [PlatformIO Core](https://docs.platformio.org/en/latest/core/installation/index.html),
  Docker Engine, and the Docker Compose plugin
- a Docker-capable host and a 2.4 GHz Wi-Fi network reachable by both host and ESP32

## 1. Check out the repository

```bash
git clone --recursive https://github.com/dkej123/zBox.git
cd zBox
git submodule status --recursive
```

For an existing non-recursive checkout, run `git submodule update --init --recursive`.

## 2. Print and assemble

Print each STL separately. Test-fit the lids, NFC slot, speaker holders, buttons, and board
before installing heat-set inserts. The STEP assembly in
[`hardware/cad/fusion360/step/`](../hardware/cad/fusion360/step/) is useful for fit changes.

Wire the four buttons on protoboard and assemble the electronics using the pin table and
load-switch circuits in [hardware wiring](hardware.md). The PN532 must be configured for SPI.
Mount the NFC antenna away from metal and keep the I2S/audio wiring short.

If using the v2.0 PCB/Gerbers, do not fit it as though it matched the current schematic. The
amplifier/NFC load switches, current button pull-ups, and NS4168 header require manual
off-board implementation. Use a continuity meter to verify every affected net listed in
[hardware status](hardware-status.md). Never connect the proposed future power latch as part
of the base build.

Before applying power:

- verify LiPo and electrolytic capacitor polarity;
- verify there is no short between power and ground;
- set the MT3608 output to 5 V before connecting the LEDs;
- confirm the USB-C footprint/receptacle match; and
- inspect all switched-power MOSFET orientation and module pinouts.

## 3. Prepare the microSD card

Format the card as FAT32 and insert it into the Lolin D32 Pro slot. A 4–16 GB card is ample.
Leave it empty: the first synchronization creates the required directories and metadata.

## 4. Build and flash firmware

From the repository root:

```bash
cd esp32
pio run -e lolin_d32_pro
pio run -e lolin_d32_pro -t upload
pio device monitor --baud 115200
```

The production build intentionally compiles most logging out. For diagnosis, flash
`lolin_d32_pro_debug` and monitor at 921600 baud. No compile-time server address is
required; the server connects to the HTTP service exposed by zBox in Sync Mode.

## 5. Start the server

On the Docker host, from the repository root:

```bash
docker compose config
docker compose up -d --build
docker compose ps
curl http://localhost:8000/api/health
```

Open `http://<server-host>:8000`. Compose persists the database/settings in `./data`, tracks
and system sounds in `./music`, and mounts `./web` into the container. Back up `data/` and
`music/`; both are intentionally ignored by Git.

You may put `ZBOX_IP=zbox.local` (or an IP address) in a local `.env`, but this is only the
fallback. The preferred configuration is stored through **Device** in the admin portal.

## 6. Provision Wi-Fi

Power on zBox and hold `A+B` for about two seconds. The device restarts into Sync Mode. If it
has no saved network, join the `zBox-Sync` access point and use its captive portal to select
the same 2.4 GHz network used by the server. The credentials are stored on the ESP32.

Find the assigned address in the router's client list or the serial log. In the server portal,
open **Device**, enter that IP or `zbox.local`, save it, and check that the device becomes
online. The portal value takes precedence over `ZBOX_IP`.

## 7. First playback

1. In **Songs**, upload an MP3.
2. In **Tags**, choose scan, present a card to the PN532, and assign the uploaded track.
3. In **Device**, start synchronization and wait for all files and mappings to complete.
4. Hold `A+B` to leave Sync Mode, then present the registered card in NFC Card Mode.

Audio should play locally from microSD through the NS4168. Bluetooth is optional: hold `A`
for about two seconds, then select a target from **Device** if needed.

## Troubleshooting

- **No `zBox-Sync` network:** enter Sync Mode with a two-second `A+B` hold; erase stored Wi-Fi
  only if reprovisioning is required, then retry close to the access point.
- **Portal shows offline:** confirm zBox is in Sync Mode, verify both hosts are on the same
  network, save the current device address under **Device**, and test `http://<zbox-ip>/diag/status`.
- **SD failure:** reformat FAT32, reseat the card, and verify `SD_CS=GPIO4` and the D32 Pro slot.
- **NFC failure:** set the PN532 to SPI and verify `SS=5`, `SCK=22`, `MISO=21`, and `MOSI=0`.
- **No local audio:** verify NS4168 `BCLK=32`, `LRCK=33`, `DIN=13`, speaker polarity, and the
  manually wired `NS_EN=15` load switch described in [hardware wiring](hardware.md).
- **Unexpected resets when audio starts:** disconnect power immediately and recheck the Q3
  soft-start parts, especially `R12=10k`, `C6=100nF`, and local decoupling.
- **Won't wake:** hold `D` for at least 400 ms; hold `C+D` to request night-light mode.

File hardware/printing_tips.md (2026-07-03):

# 3D Printing Tips

Practical print orientation and support notes for the zBox enclosure parts.
Part names follow the CAD/STL naming used in this repository.

## Part Settings

| Part | Print orientation | Supports | Notes |
| --- | --- | --- | --- |
| `front_lid` | Any convenient orientation | No | The part should print cleanly without support material. |
| `nfc_card_slot` | Place it on the bottom/base face | Usually no | Keep the base flat on the build plate for the cleanest fit. |
| `rear_lid` | Place it on the inner face | Yes | Supports are needed around the ESP cutout. |
| `shell` | Place it on the front face | Yes | The front face is the side closer to the button cutout. |
| `speaker_holders` | Place each holder on its side, using the largest flat face | Usually no | This gives the part the most stable contact with the build plate. |
| `wall` | Place it on the bottom/base face | Usually no | Use the flat base as the build-plate contact surface. |

## General Notes

- Preview generated supports in the slicer before printing.
- Keep visible exterior faces away from support contact whenever possible.
- If the fit is tight, test-fit the lids and NFC card slot before final assembly.

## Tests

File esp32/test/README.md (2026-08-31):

# zBox — test documentation

## Overview

The firmware test strategy is now host-side only.

All maintained tests live under `esp32/test/test_*` and run in PlatformIO `native` environments. There are no serial integration tests, tester-firmware flows, or manual hardware test scripts in this repository anymore.

## Running

```bash
cd esp32
pio platform install native   # one-time
pio test -e native -v
pio test -e native_btndec -v
```

## Suites

### `test_uid_format` (7 tests)

Tests `uidToString()` formatting rules for NFC UIDs:

- 4-byte and 7-byte UIDs
- uppercase hex output
- zero padding regression cases
- all-zero and single-byte inputs

### `test_volume` (21 tests)

Tests pure helpers:

- output-volume clamp/step logic
- battery-to-bars thresholds

### `test_mapping` (8 tests)

Tests JSON mapping parsing behavior:

- valid and invalid `mappings.json`
- empty and missing `figurines`
- lookup for known and unknown UIDs

### `test_reducer` (21 tests)

Tests the pure `reduce(AppState, Event, now_ms)` state machine:

- boot readiness and startup autoplay
- `PlaybackModeLoaded`, `MappingsLoaded`, `VolumeLoaded`
- NFC playback and music playback transitions
- play/pause/next/prev behavior
- BT headphones mode lifecycle
- sleep flow, power-off sound, BT stop-before-sleep
- battery preview and volume overlay deadlines

### `test_bt_adapter` (3 tests)

Tests the BT adapter contract:

- start while headphones are already connected
- connection-edge event emission
- stop completion without false disconnect events

### `test_audio_adapter` (7 tests)

Tests critical audio-adapter failure paths:

- missing NFC mapping
- missing music index
- missing or unknown system sound
- queue rejection for playback/system sound
- best-effort `AudioStopped` on failed stop enqueue

### `test_dispatcher` (4 tests)

Tests dispatcher timeout handling:

- NFC playback start timeout
- system-sound timeout
- stop timeout
- pending registry cleanup after feedback

### `test_button_decoder` (27 tests, `native_btndec`)

Tests pure button decoding:

- single and double click behavior
- short `BTN_C` / `BTN_D` volume actions
- long `BTN_A` -> BT headphones mode request
- long `BTN_C` -> battery preview request
- long `BTN_B` -> mode toggle
- long `BTN_D` -> normal sleep request
- combo `A+B` -> Sync Mode request
- debounce and swallowed-release regressions

## Scope

These tests cover the maintained architectural contracts:

- pure reducer logic
- dispatcher timeout behavior
- adapter-level failure handling
- button decoding
- target firmware compilation via `pio run -e lolin_d32_pro`

They do not simulate real ESP32 peripherals or radio stacks. NFC silicon behavior, SD timing, deep sleep wake causes, and actual Bluetooth stack behavior still require manual hardware validation outside this repo.

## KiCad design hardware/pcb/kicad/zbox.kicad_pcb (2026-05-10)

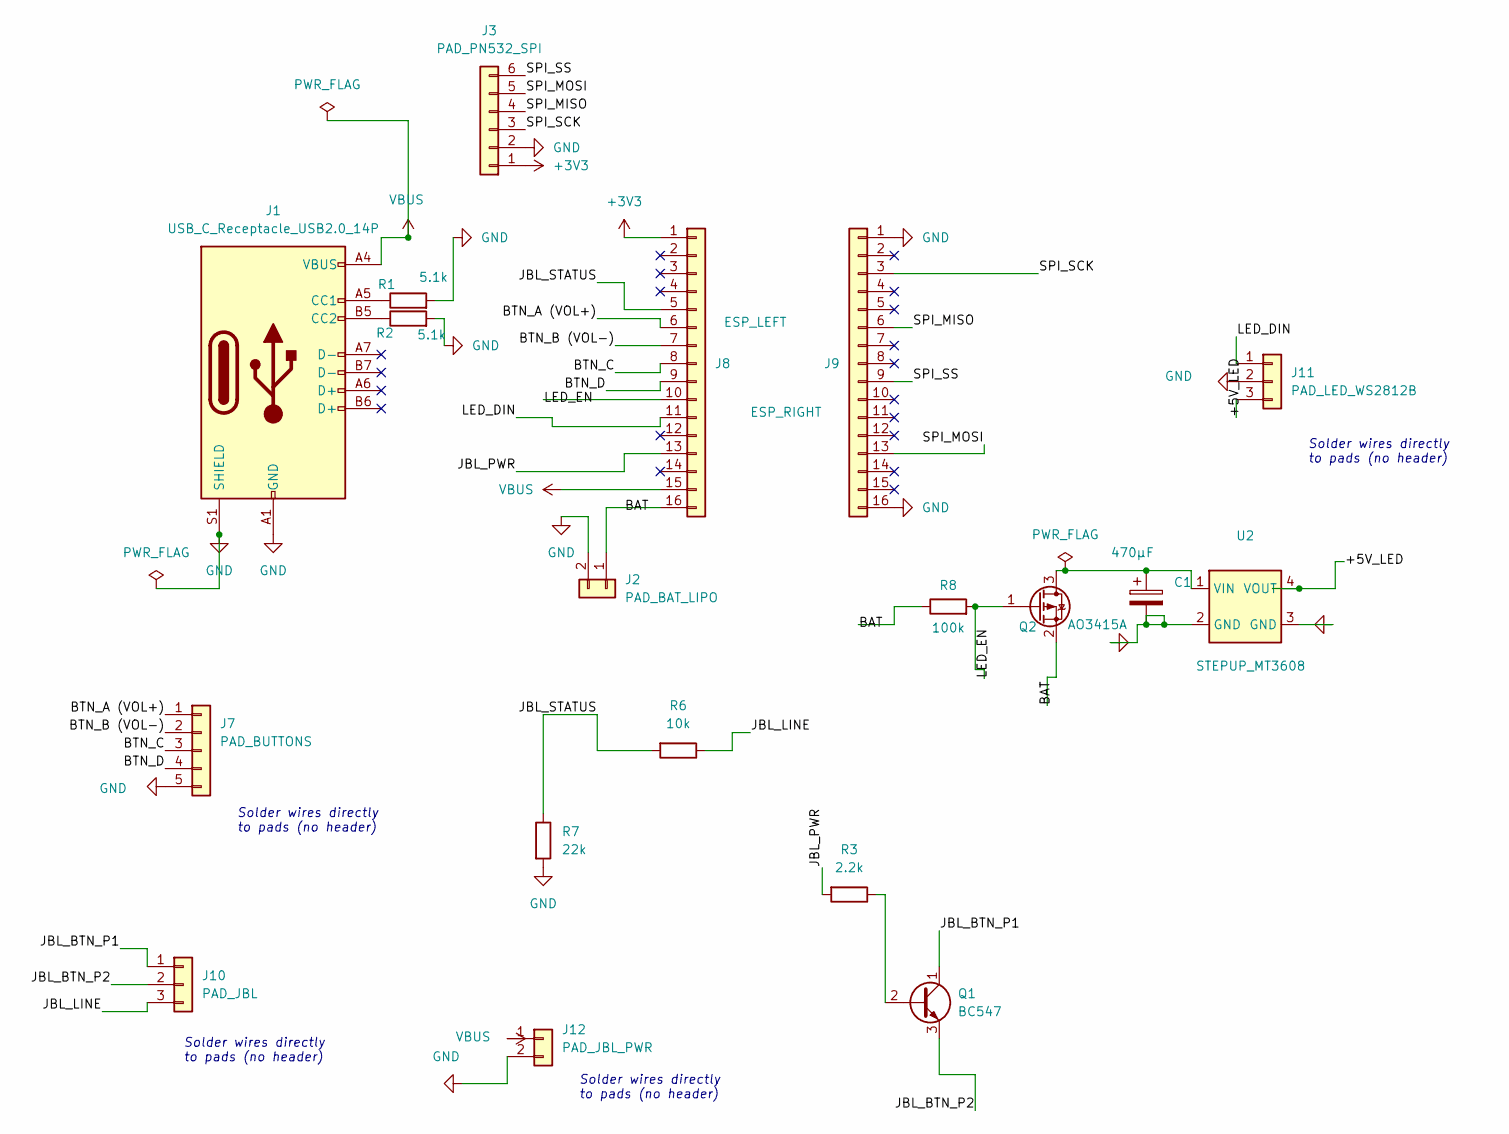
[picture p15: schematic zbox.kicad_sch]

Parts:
C1: 470µF; CP_Radial_D8.0mm_P3.50mm
J1: USB_C_Receptacle_USB2.0_14P; USB_C_Receptacle_GCT_USB4085
J2: PAD_BAT_LIPO; SolderPad_1x02_W2.2mm_H3mm_P2.7mm
J3: PAD_PN532_SPI; SolderPad_1x06_W2.2mm_H3mm_P2.7mm
J7: PAD_BUTTONS; SolderPad_1x05_W2.2mm_H3mm_P2.7mm
J8: ESP_LEFT; PinHeader_1x16_P2.54mm_Vertical
J9: ESP_RIGHT; PinHeader_1x16_P2.54mm_Vertical
J10: PAD_JBL; SolderPad_1x03_W2.2mm_H3mm_P2.7mm
J11: PAD_LED_WS2812B; SolderPad_1x03_W2.2mm_H3mm_P2.7mm
J12: PAD_JBL_PWR; SolderPad_1x02_W2.2mm_H3mm_P2.7mm
Q1: BC547; TO-92_Inline
Q2: AO3415A; SOT-23
R1, R2: 5.1k; R_Axial_DIN0207_L6.3mm_D2.5mm_P10.16mm_Horizontal
R3: 2.2k; R_Axial_DIN0207_L6.3mm_D2.5mm_P10.16mm_Horizontal
R6: 10k; R_Axial_DIN0207_L6.3mm_D2.5mm_P10.16mm_Horizontal
R7: 22k; R_Axial_DIN0207_L6.3mm_D2.5mm_P10.16mm_Horizontal
R8: 100k; R_Axial_DIN0207_L6.3mm_D2.5mm_P10.16mm_Horizontal
U2: STEPUP_MT3608; MT3608_Pancake

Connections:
+3V3: J3.1, J8.1
/+5V_LED: J11.3, U2.4 (VOUT)
/BAT: J2.1, J8.16, Q2.2 (S), R8.1
/BTN_A (VOL+): J7.1, J8.6
/BTN_B (VOL-): J7.2, J8.7
/BTN_C: J7.3, J8.8
/BTN_D: J7.4, J8.9
/JBL_BTN_P1: J10.1, Q1.1 (C)
/JBL_BTN_P2: J10.2, Q1.3 (E)
/JBL_LINE: J10.3, R6.1
/JBL_PWR: J8.13, R3.2
/JBL_STATUS: J8.5, R6.2, R7.1
/LED_DIN: J8.11, J11.1
/LED_EN: J8.10, Q2.1 (G), R8.2
/SPI_MISO: J3.4, J9.6
/SPI_MOSI: J3.5, J9.13
/SPI_SCK: J3.3, J9.3
/SPI_SS: J3.6, J9.9
GND: C1.2, J1.A1 (GND), J1.A12 (GND), J1.B1 (GND), J1.B12 (GND), J1.S1 (SHIELD), J2.2, J3.2, J7.5, J9.1, J9.16, J11.2, J12.2, R1.2, R2.2, R7.2, U2.2 (GND), U2.3 (GND)
unnamed: J1.A5 (CC1), R1.1
unnamed: J1.B5 (CC2), R2.1
unnamed: Q1.2 (B), R3.1
unnamed: C1.1, Q2.3 (D), U2.1 (VIN)
VBUS: J1.A4 (VBUS), J1.A9 (VBUS), J1.B4 (VBUS), J1.B9 (VBUS), J8.15, J12.1

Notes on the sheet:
Solder wires directly to pads (no header)

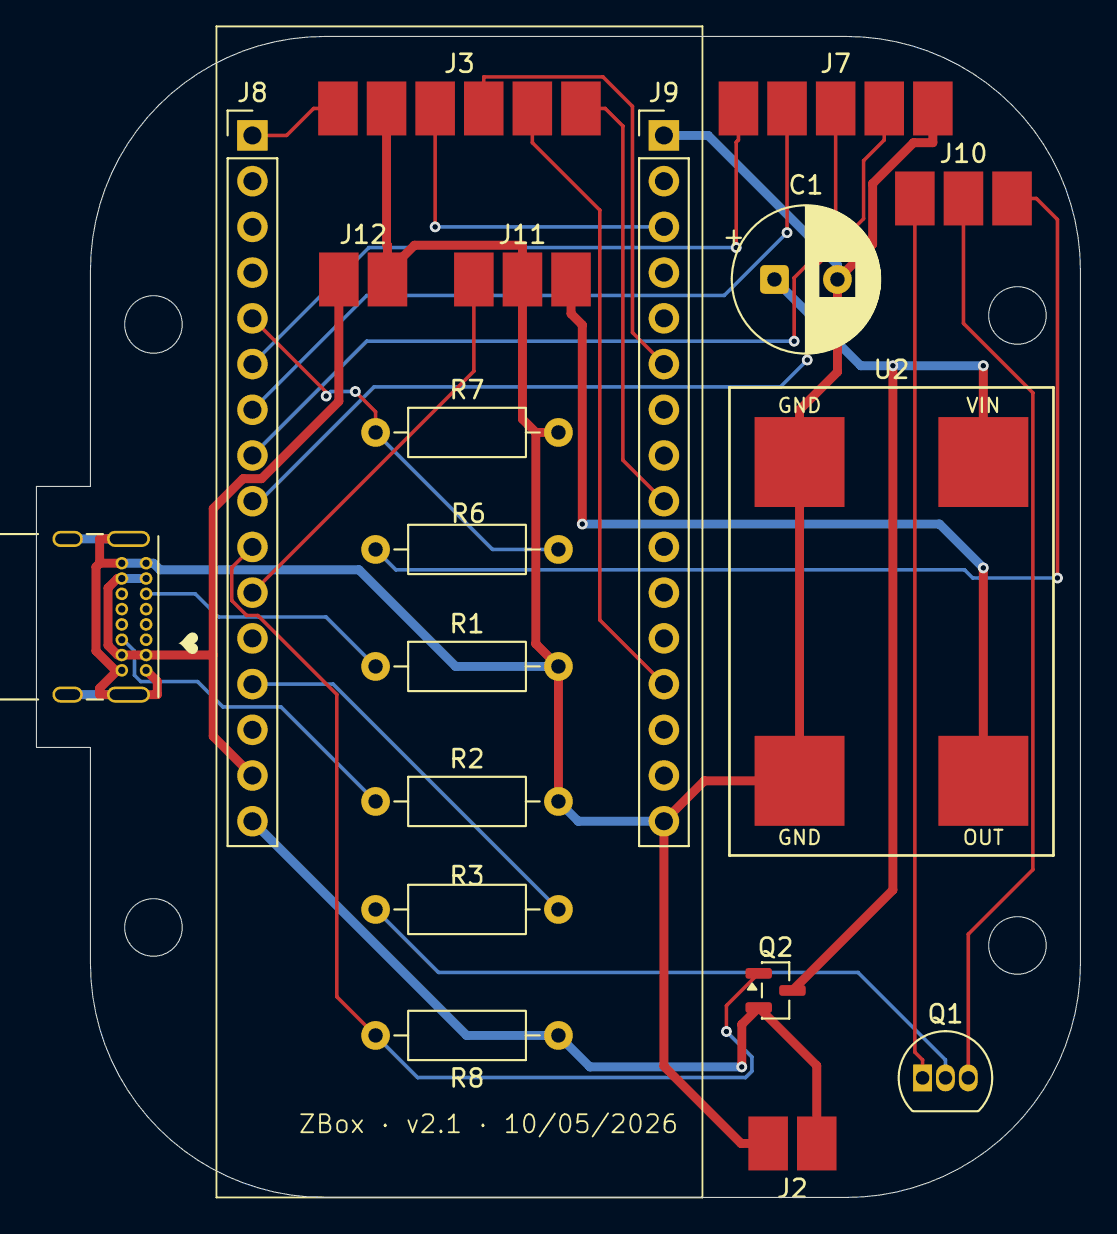
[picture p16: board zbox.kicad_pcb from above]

Board: 2 copper layers, 58.0 x 64.5 mm, 19 parts (0 on the bottom side), 24 nets.

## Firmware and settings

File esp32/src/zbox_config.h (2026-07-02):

#pragma once

#define ENABLE_LEDS true
#define ENABLE_NFC true

// =============================================================================
// Pins
// =============================================================================

#define SD_CS 4 // SD card CS on the built-in Lolin D32 Pro slot

// PN532 NFC (software SPI)
#define PN532_SCK 22
#define PN532_MISO 21
#define PN532_MOSI 0
#define PN532_SS 5
#define NFC_EN 12  // Low-side N-MOSFET gate: HIGH = PN532 on, LOW = off

#define LED_PIN 14  // WS2812B DIN
#define LED_EN  27  // P-MOSFET gate (AO3415A): LOW = LEDs on, HIGH = off
#define LED_COUNT 12
#define LED_BRIGHTNESS 40

#define BTN_A 36 // VP / input-only, external pull-up required
#define BTN_B 39 // VN / input-only, external pull-up required
#define BTN_C 25 // VOL- (RTC)
#define BTN_D 26 // VOL+ (RTC, deep-sleep wake through ext0)
#define BTN_COUNT 4

#define AUDIO_I2S_BCLK 32
#define AUDIO_I2S_LRCK 33
#define AUDIO_I2S_DOUT 13
#define NS_EN 15 // High-side P-MOSFET gate: LOW = NS4168 on, HIGH = off
#define BAT_ADC_PIN 35 // GPIO35 (I35) reads the onboard D32 Pro battery divider
#define BAT_ADC_DIVIDER_RATIO 2.0f // D32 Pro: VBAT --100k-- GPIO35 --100k-- GND
#define BAT_ADC_CALIBRATION 0.983f // Per-device ADC calibration factor

// Active low-voltage cutoff: while the device is running, a sustained critical
// voltage forces a normal deep sleep (power-off sound + shutdown) instead of
// discharging the cell down to the pack's PCM cutoff (~2.5 V). No hardware latch
// exists, so deep sleep is the lowest state firmware can reach.
#define BAT_CRITICAL_VOLTAGE 3.30f    // force deep sleep below this
#define BAT_CRITICAL_RELEASE_V 3.40f  // hysteresis: reset the low counter above this
#define BAT_CRITICAL_POLL_MS 15000UL  // sampling cadence while awake
#define BAT_CRITICAL_CONSECUTIVE 3    // consecutive lows before sleeping (~45 s debounce)

// =============================================================================
// Configuration
// =============================================================================

#define LONG_PRESS_MS 2000
#define DOUBLE_CLICK_WINDOW_MS 350
#define WAKE_ABORT_MS 400
#define NIGHT_LIGHT_SLEEP_HOLD_MS 1000
#define DEBOUNCE_MS 20
#define NFC_READ_INTERVAL 1000
#define NFC_PRESENT_POLL_INTERVAL_MS NFC_READ_INTERVAL
#define NFC_BOOT_INIT_DELAY_MS 250
#define NFC_BOOT_MAPPING_DELAY_MS 350
#define NFC_ERROR_THRESHOLD 10
#define NFC_TAG_LOST_MS 1500  // Require a sustained missing read before treating the tag as removed
#define NFC_LOST_POLL_INTERVAL_MS 150
#define PN532_WAKE_SETTLE_MS 5
#define AUDIO_BUF_SIZE 2048

// Output volume
#define SYSTEM_SOUND_VOL_PERCENT 20
#define NIGHT_LIGHT_BRIGHTNESS_STEP 10
#define NIGHT_LIGHT_BRIGHTNESS_MIN 10
#define NIGHT_LIGHT_BRIGHTNESS_MAX 100
#define NIGHT_LIGHT_BRIGHTNESS_DEFAULT 50

// Idle timeout -> deep sleep
#define IDLE_TIMEOUT_MS (10UL * 60 * 1000) // 10 minutes without playback
#define NIGHT_LIGHT_TIMEOUT_MS (15UL * 60 * 1000)

// Sync / service mode
#define WIFI_HOSTNAME "zbox"
#define SYNC_PENDING_PATH "/data/sync_pending"
#define SYNC_AP_NAME "zBox-Sync"
#define SYNC_HTTP_PORT 80
#define SYNC_OTA_PORT 3232
#define SYNC_LOG_INTERVAL_MS 5000

// Bluetooth target speaker (NVS-backed, changeable from web portal)
#define BT_TARGET_NVS_KEY   "bt_target"
#define BT_TARGET_MAC_NVS_KEY "bt_mac"
#define BT_DEFAULT_NAME     "zBox Headphones"
#define BT_SCAN_MAX_RESULTS 12
#define BT_SCAN_NAME_MAX    64

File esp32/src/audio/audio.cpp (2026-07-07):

#include "audio.h"
#include <Arduino.h>
#include <SD.h>
#include <climits>
#include <cstring>
#include "AudioTools.h"
#include "AudioTools/AudioCodecs/CodecMP3Helix.h"
#include "BluetoothA2DPSource.h"
#include "dispatcher.h"
#include "event_queue.h"
#include "events.h"
#include "leds.h"
#include "logging.h"
#include "pcm_volume.h"
#include "persistent_log.h"
#include "persistence_adapter.h"
#include "peripheral_power.h"
#include "state.h"
#include "volume_scale.h"
#include "zbox_config.h"
#include <esp_bt.h>
#include <esp_heap_caps.h>
#include <esp_bt_main.h>
#include <freertos/FreeRTOS.h>
#include <freertos/portmacro.h>

namespace {

static char s_btTargetName[64] = BT_DEFAULT_NAME;
static char s_btTargetMac[18] = {};

static void writeSilenceGap(uint16_t durationMs); // forward declaration
constexpr size_t VOLUME_SCRATCH_SAMPLES = 256;
constexpr uint16_t TRACK_TRANSITION_SILENCE_MS = 40;
constexpr size_t LOCAL_AUDIO_READ_CHUNK_SIZE = AUDIO_BUF_SIZE;
constexpr size_t BT_AUDIO_READ_CHUNK_SIZE = 512;
constexpr size_t BT_A2DP_WRITE_FRAME_SIZE = 512;
constexpr size_t BT_PCM_BUFFER_SIZE = 512 * 30;
constexpr uint16_t BT_PCM_WRITE_TIMEOUT_MS = 12;
static_assert(LOCAL_AUDIO_READ_CHUNK_SIZE <= AUDIO_BUF_SIZE, "local audio read chunk exceeds buffer");
static_assert(BT_AUDIO_READ_CHUNK_SIZE <= AUDIO_BUF_SIZE, "BT audio read chunk exceeds buffer");

enum class AudioCmdType : uint8_t { PLAY, STOP, PAUSE, RESUME, VOLUME };

struct AudioCmd {
    AudioCmdType type;
    char path[256];
    int volumePercent;
    uint16_t gapMs;
    CmdId cmd_id;
    uint8_t sound_id;
    char uid[24];
    uint16_t track_index;
    bool is_nfc_track;
    bool is_system_sound;
};

class BeatTracker : public AudioOutput {
public:
    void setSink(Print* sink) { sink_ = sink; }
    void setVolumePercent(int percent) { volume_percent_ = constrain(percent, 0, 100); }

    void reset() {
        memset(hist_, 0, sizeof(hist_));
        hist_index_ = 0;
        hist_count_ = 0;
        last_beat_ms_ = 0;
        dither_state_ = {};
    }

    size_t write(const uint8_t* data, size_t len) override {
        if (len >= 2) detectBeat(data, len);
        if (!sink_) return len;

        const int percent = volume_percent_;
        if (percent >= 100) {
            return sink_->write(data, len);
        }
        if (percent <= 0) {
            static uint8_t silence[512] = {};
            size_t remaining = len;
            size_t written_total = 0;
            while (remaining > 0) {
                const size_t chunk = remaining > sizeof(silence) ? sizeof(silence) : remaining;
                const size_t written = sink_->write(silence, chunk);
                written_total += written;
                if (written != chunk) break;
                remaining -= written;
            }
            return written_total;
        }

        size_t written_total = 0;
        size_t offset = 0;
        while (offset < len) {
            const size_t bytes = (len - offset) > (VOLUME_SCRATCH_SAMPLES * sizeof(int16_t))
                ? (VOLUME_SCRATCH_SAMPLES * sizeof(int16_t))
                : (len - offset);
            const size_t samples = bytes / sizeof(int16_t);
            const int16_t* in = reinterpret_cast<const int16_t*>(data + offset);
            for (size_t i = 0; i < samples; ++i) {
                scratch_[i] = scalePcm16Sample(in[i], static_cast<uint8_t>(percent), dither_state_);
            }
            const size_t written = sink_->write(reinterpret_cast<const uint8_t*>(scratch_),
                                                samples * sizeof(int16_t));
            written_total += written;
            if (written != samples * sizeof(int16_t)) break;
            offset += samples * sizeof(int16_t);
        }
        return written_total;
    }

private:
    void detectBeat(const uint8_t* data, size_t len) {
        const int16_t* s = reinterpret_cast<const int16_t*>(data);
        const int n = (int)(len / 2);
        uint64_t sum = 0;
        for (int i = 0; i < n; i++) {
            const int32_t v = s[i];
            sum += (uint32_t)(v * v);
        }
        const uint32_t e = n > 0 ? (uint32_t)(sum / (uint32_t)n) : 0;

        hist_[hist_index_] = e;
        hist_index_ = (hist_index_ + 1) % HIST;
        if (hist_count_ < HIST) hist_count_++;

        uint64_t avg = 0;
        for (int i = 0; i < hist_count_; i++) avg += hist_[i];
        avg = hist_count_ > 0 ? avg / hist_count_ : 0;

        if (avg > 0) {
            const uint32_t ratio = (uint32_t)((uint64_t)e * 150 / avg);
            g_audioEnergy = (uint8_t)(ratio < 55 ? 55 : ratio > 240 ? 240 : ratio);
        }

        const unsigned long now = millis();
        if (avg > 0 && (uint64_t)e > avg + avg / 5 && (now - last_beat_ms_) > 150) {
            last_beat_ms_ = now;
            g_beatDetected = true;
        }
    }

    static constexpr int HIST = 43;
    Print* sink_ = nullptr;
    int volume_percent_ = volumeLevelToPercent(OUTPUT_VOL_LEVEL_DEFAULT);
    uint32_t hist_[HIST] = {};
    int hist_index_ = 0;
    int hist_count_ = 0;
    unsigned long last_beat_ms_ = 0;
    PcmVolumeDitherState dither_state_{};
    int16_t scratch_[VOLUME_SCRATCH_SAMPLES] = {};
};

class BtFrameAlignedSink : public Print {
public:
    void setSink(Print* sink) { sink_ = sink; }

    void reset() {
        pending_len_ = 0;
        memset(pending_, 0, sizeof(pending_));
    }

    size_t write(uint8_t value) override {
        return write(&value, 1);
    }

    size_t write(const uint8_t* data, size_t len) override {
        if (!sink_) return len;

        size_t consumed = 0;
        while (consumed < len) {
            const size_t room = sizeof(pending_) - pending_len_;
            const size_t take = (len - consumed) < room ? (len - consumed) : room;
            memcpy(pending_ + pending_len_, data + consumed, take);
            pending_len_ += take;
            consumed += take;

            if (pending_len_ == sizeof(pending_)) {
                const size_t written = sink_->write(pending_, sizeof(pending_));
                if (written != sizeof(pending_)) {
                    pending_len_ = 0;
                    return consumed;
                }
                pending_len_ = 0;
            }
        }
        return len;
    }

    int availableForWrite() override {
        return sink_ ? sink_->availableForWrite() : 0;
    }

private:
    Print* sink_ = nullptr;
    uint8_t pending_[BT_A2DP_WRITE_FRAME_SIZE] = {};
    size_t pending_len_ = 0;
};
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

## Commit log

2026-03-20 dziala ale szumi
    [musicbox-B_Cu.gbr, musicbox-B_Mask.gbr, musicbox-B_Paste.gbr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]
2026-03-24 workin bt solution
    [custom_4mb_noota.csv]
2026-04-30 krok 1: usuń martwy kod (currentNfcUid, lastNfcRead, noTagCount)
2026-04-30 krok 2: scope cleanup — anon namespace, static local
    - nfcErrorCount, bootStart, bootTimingDone → anonymous namespace
    - bothCDHandled → static local w handleButtons()
2026-05-01 test: native unit tests — uid format, volume, battery, mapping
    31 testów native (PlatformIO + Unity, bez hardware):
    - test_uid_format: 7 testów uidToString() (padding, uppercase, separatory)
    - test_volume: 6 testów volume clamp + 10 testów batteryBars()
    - test_mapping: 8 testów loadMappings() z ArduinoJson v7
2026-05-01 test: serial harness + boot sequence and timing integration tests
    SerialHarness: reader thread, wait_for_line/sequence, DTR reset.
    test_boot_sequence: 5 testów kolejności logów przy normalnym boot.
    test_timing: 4 testy progów T+ (GPIO <200ms, SD <500ms, NFC <2500ms, BT <3000ms).
2026-05-01 test: tester ESP32-S3 firmware (button simulation)
    Firmware dla drugiego ESP32-S3 (N16R8). Komendy serial: PRESS/PRESS_COMBO/RELEASE ALL/PING.
    Release = Hi-Z (INPUT), nigdy OUTPUT HIGH. Safety timeout 10s.
    GPIO: OUT_A=4, OUT_B=5, OUT_C=6, OUT_D=7.
2026-05-01 test: button automation tests (volume, battery, sleep, sync)
    ButtonTester: sterowanie tester ESP32-S3 przez serial.
    6 testów @requires_tester: VOL+/VOL-, BAT voltage range,
    deep sleep trigger, sync mode (flag + restart + SYNC MODE log).
2026-05-01 test: manual NFC playback tests
    4 testy @manual: place figurka → startPlayback + PLAYBACK START,
    uid format validation ([0-9A-F]{2}(:[0-9A-F]{2}){3,6}),
    remove → stopPlayback, audio telemetry SD=N B/s.
2026-05-01 test: update PROGRESS.md — etap 1 zielony (31/31)
2026-05-01 test: fix integration tests — boot/timing/heartbeat 15/15 PASS
    Naprawione problemy:
    - conftest: session fixture nie resetuje (double-reset przerywał boot)
    - serial_harness: dodano wait_for_nth_occurrence() do śledzenia N wystąpień
    - test_timing: BT start próg 3000→5000ms (empirycznie T+3638ms)
    - test_heartbeat: brak resetu w heartbeat testach (obserwacja działającego
    device eliminuje problem kumulatywnych resetów BT)
    - conftest: auto-skip dla @manual i @requires_hardware (nowe opcje
    --run-manual, --run-hardware)
2026-05-01 test: update PROGRESS.md — etapy 1-3 zielone (46/46)
2026-05-01 docs: dokumentacja testów (tests/README.md)
    Pełna dokumentacja wszystkich 6 etapów testów:
    - co każdy test sprawdza, tabele wzorców i progów
    - infrastruktura (SerialHarness, ButtonTester, conftest fixtures)
    - wymagania sprzętowe per etap
    - znane zachowania hardware (BT reconnect, IDLE_TIMEOUT)
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2026-05-01 refactor: przenieś wszystkie testy do esp32/test/
    tests/ → esp32/test/integration/ (Python integration tests)
    tests/requirements.txt → esp32/test/requirements.txt
    tests/PROGRESS.md → esp32/test/PROGRESS.md
    Zaktualizowano ścieżki w README.md i PROGRESS.md.
    Katalog tests/ usunięty.
2026-05-02 refactor: extract musicbox_config.h, logging.h, helpers.h
    - musicbox_config.h: wszystkie #define (piny, stałe, timeouty, BTN_COUNT)
    - logging.h: makra LOG/LOGLN
    - helpers.h: inline pure functions — urlEncode, uidToString, batteryBars
    - test_uid_format.cpp: zastąp inline kopię uidToString #include helpers.h
    - test_volume.cpp: zastąp inline kopię batteryBars #include helpers.h
    - 31/31 native tests zielone
2026-05-02 refactor: extract shared_types and state skeleton
    - shared_types.h: Button struct, NfcEvent struct (TYLKO te dwa)
    - state.h: extern deklaracje shared globals
    - state.cpp: definicje shared globals (przeniesione z main.cpp)
    - main.cpp: usuwa duplikaty, dodaje #include shared_types/state
    - bootStart/bootTimingDone: z anonimowego namespace do state.cpp
    - nfcErrorCount: static (→ nfc_module.cpp w kroku 7)
    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
2026-05-02 refactor: extract battery module
    - battery.h/.cpp: readBatteryVoltage() — hardware ADC read
    - batteryBars() pozostaje w helpers.h (używany przez buttons.cpp)
    - main.cpp: usuwa definicję, dodaje #include battery.h
    - lolin_d32_pro build OK
2026-05-02 refactor: extract leds module
    - leds.h/.cpp: LED task, animacje, cały state prywatny (leds[], ledMode, etc.)
    - ENABLE_LEDS przeniesiony do musicbox_config.h
    - API: ledInit, ledPreInitHardware, ledSuspendTask, ledResumeTask,
    ledClear, ledSetWakeProgress, ledPowerOff, ledGetTaskHWM,
    ledSetBootProgress, ledSetWaitBt, ledSetIdle, ledSetPlaying,
    ledShowVolume, ledSetSyncWifi, ledSetSyncProgress,
    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
2026-05-02 refactor: extract sd_storage module
    Move initSD, readJsonFromSd, loadMappings, loadSystemSounds into
    sd_storage.h/.cpp. Remove unused Preferences.h include from main.cpp.
    SD/SPI includes stay in main.cpp until sync_mode and audio are extracted.
2026-05-02 refactor: extract nfc_module
    Move Adafruit_PN532, nfcMutex, nfcQueue, nfcTaskHandle,
    nfcTaskStopRequested, rtcNfcPowerDownSent, nfcErrorCount,
    all raw SPI helpers, nfcInitSequence, reinitNfc, readNfcTag,
    nfcTaskFunc, and nfcPowerDown into nfc_module.h/.cpp.
    Public API: nfcInit, nfcPrescan, nfcStartTask, nfcGetEvent,
    nfcStopTaskForSleep, nfcPowerDown, nfcGetTaskHWM.
    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
2026-05-02 refactor: extract buttons_isr (ISR + init only)
    Move Button buttons[], btnISR IRAM_ATTR, and buttonsInit()
    from main.cpp to buttons_isr.h/.cpp. buttons[] is extern,
    accessible to buttons.cpp in the next step.
2026-05-02 refactor: extract buttons action handler
    Move handleButtons() from main.cpp to buttons.h/.cpp.
2026-05-02 refactor: cleanup main.cpp to setup() + loop() only
    Remove includes no longer needed in main.cpp (WiFi, ArduinoJson,
    SPI, map, set, esp_bt — all moved to their modules).
    main.cpp is now 361 lines: setup() + loop() + module includes.
    [main.cpp]
2026-05-05 dziala wszystko, zmiana sync mode gotowa
    [custom_4mb_ota.csv]
2026-05-08 for github
    [musicbox-B_Cu.gbr, musicbox-B_Mask.gbr, musicbox-B_Paste.gbr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]
2026-05-16 glosnik przez modul dziala i naprawione bugi po refacotrze oraz kilka usrpawnien
    [audio.cpp]
2026-06-01 wszystko dziala, nie dziala rozlaczanie slcuhawek bo crash
    [audio.cpp, main.cpp, zbox_config.h]
2026-07-01 Fixes for audio stutter and extra logging for esp
    [zbox.kicad_sch]
2026-07-01 disable logs for prod build, introduce prod build, introduce go to sleep when low voltage
2026-07-03 Repo cleanup
    [front_lid_zbox_clear.stl, nfc_card_slot_zbox_clear.stl, rear_lid_zbox_clear.stl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]
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2026-07-07 documentation update, small fixes
    [zbox.kicad_sch]
2026-09-16 fix: replace absolute local path in KiCad sym-lib-table with relative URI
    Avoids leaking the local filesystem username/path structure in the
    public repository.
